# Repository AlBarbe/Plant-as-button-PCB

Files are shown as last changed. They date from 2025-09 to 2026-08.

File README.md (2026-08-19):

<!-- HEADER -->
# Plant as Button — PCB 🌱🔌

Wouldn't be cool to use as a plant a touch sensor? Now it has a proper board to live on.
This repo hosts the hardware side of the project — the companion firmware (the code that actually reads the plant's touch) lives in [Plant-as-button](https://github.com/AlBarbe/Plant-as-button).

<!-- TABLE OF CONTENTS -->
<!--
<details>
  <summary>Table of contenent</summary>
    <ul>
      <li></li><a href="#introduction">Introduction</a></li>
      <li></li><a href="#how-it-works">How it works</a></li>
      <li></li><a href="#repository-structure">Repository structure</a></li>
      <li></li><a href="#status--known-issues">Status & known issues</a></li>
    </ul>
</details>
-->
<!-- INTRODUCTION -->
## Introduction

This is my first PCB design, done in KiCad 9. The idea was to give the plant-as-button concept a real, standalone board instead of a breadboard: an ESP32-S3 module, its own power supply, and a driver stage so the "button" can actually control something (an RGBWW LED strip) when the plant is touched.

The board has been manufactured and it works. Every opinion or suggestion is more than welcome!!

<!-- HOW IT WORKS -->
## How it works
- ### Concept
  The board is built around an ESP32-S3-MINI-1 module, using the same capacitive touch trick described in the firmware repo: a touch-capable GPIO is wired to a pad, meant to be connected (by a simple cable) to the soil near the plant's roots. When a person touches the plant, the capacitance seen on that GPIO changes, and the microcontroller reads it as a "press".

- ### Power
  The board can be powered either from USB-C or from an external 12V supply (screw terminal), with a power mux (TPS2116) automatically selecting between the two. From there, two buck converters step the voltage down to 5V and then 3.3V for the MCU and the rest of the logic. The 12V input is protected with a TVS diode, and the USB data lines have their own ESD protection.

- ### LED driver
  Five low-side MOSFETs let the ESP32 switch a common-anode RGBWW LED strip (Red, Green, Blue, Warm White, Cool White), connected via a 6-pin screw terminal. The idea is the same as the firmware's trigger class: on touch, on release, or after a given time, drive one of the channels.

- ### Debug breakout
  Basically every GPIO of the module is broken out to its own test pad on the silkscreen (labeled with the pin function, not just a generic reference), on top of the usual RESET/BOOT buttons. This turned out to be very handy, see below.

## Repository structure
- `PAB_V1.kicad_pro / .kicad_sch / .kicad_pcb` — the KiCad 9 project (schematic + 4-layer PCB, single sheet).
- `Libraries/` — symbols, footprints and 3D models used by the project (kept local so the repo is self-contained).
- `Datasheets/` — datasheets of the main parts used.
- `BOM.ods` — bill of materials.

## Status & known issues
The board has been fabricated and is working. There is one known bug: the USB-UART bridge (CP2102) is not wired correctly to the ESP32-S3, so programming/monitoring through the on-board USB-C via the CP2102 doesn't work.
It's not a dead end though — the ESP32-S3 has its own native USB, and since every GPIO (including the native USB D+/D-) is broken out to a test pad, the board can still be flashed and debugged by using those pins directly, bypassing the CP2102 entirely.

## Implementation
Firmware-wise, this board is meant to be paired with the code from [Plant-as-button](https://github.com/AlBarbe/Plant-as-button): the touch pad on this PCB is where the plant's cable connects, and the LED terminal is a ready-made output for whatever trigger logic you build on top of it.

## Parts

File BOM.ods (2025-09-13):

DESIGNATOR | QTY | VALUE | MANUF. PART N° | MANUFACTUR | PACKAGE | DESCRIPTION | LINKS
U1 | 1 |  | ESP32-WROOM-32E-N4 | Espressif System | 38-SMD Module | RF TXRX MOD BT WIFI TH SMD | https://www.digikey.com/en/products/detail/espressif-systems/ESP32-WROOM-32E-N4/11613125, https://www.snapeda.com/parts/ESP32-WROOM-32E%20(4MB)/Espressif%20Systems/view-part/?company=Private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
U2 | 1 |  | CP2102NA02GQFN20 | Silicon Labs |  | USB Bridge, USB to UART USB 2.0 UART Interface 20-QFN (3x3) | https://www.digikey.com/en/products/detail/silicon-labs/CP2102N-A02-GQFN20/9863475, https://www.snapeda.com/parts/CP2102NA02GQFN20/Silicon%20Labs/view-part/?t=cp2102&ab_test_case=b
U3 | 1 |  | USBLC6-2SC6 | STMicroelectronics | SOT-23-6 | 17V Clamp 5A (8/20µs) Ipp Tvs Diode Surface Mount SOT-23-6 | https://www.digikey.com/en/products/detail/stmicroelectronics/USBLC6-2SC6/1040559, https://www.snapeda.com/parts/USBLC6-2SC6/STMicroelectronics/view-part/?t=usblc6&ab_test_case=b
U4 | 1 |  | AP63205WU-7 | Diodes Incorporated | TSOT-23-6 | Buck Switching Regulator IC Positive Fixed 5V 1 Output 2A SOT-23-6 Thin, TSOT-23-6 | https://www.digikey.com/en/models/9858424
Q3 | 1 |  | AO3400A | Alpha & Omega Semiconductor Inc. | SOT-23-3 | N-Channel 30 V 5.7A (Ta) 1.4W (Ta) Surface Mount SOT-23-3
S1-S2 | 2 |  | PTS647SN50SMTR2 LFS | C&K |  | Tactile Switch SPST-NO Top Actuated Surface Mount
C1 | 1 | 10 µF | CL31B106KAHNNNE | Samsung Electro-Mechanics | 1206 (3216 Metric) | 10 µF ±10% 25V Ceramic Capacitor X7R 1206 (3216 Metric)
C2-C3 | 2 | 22 µF | CL31A226KAHNNNE | Samsung Electro-Mechanics | 1206 (3216 Metric) | 22 µF ±10% 25V Ceramic Capacitor X5R 1206 (3216 Metric)
C4 | 1 | 0.1 µF | GRM155R71E104KE14D | Murata Electronics | 0402 (1005 Metric) | 0.1 µF ±10% 25V Ceramic Capacitor X7R 0402 (1005 Metric)

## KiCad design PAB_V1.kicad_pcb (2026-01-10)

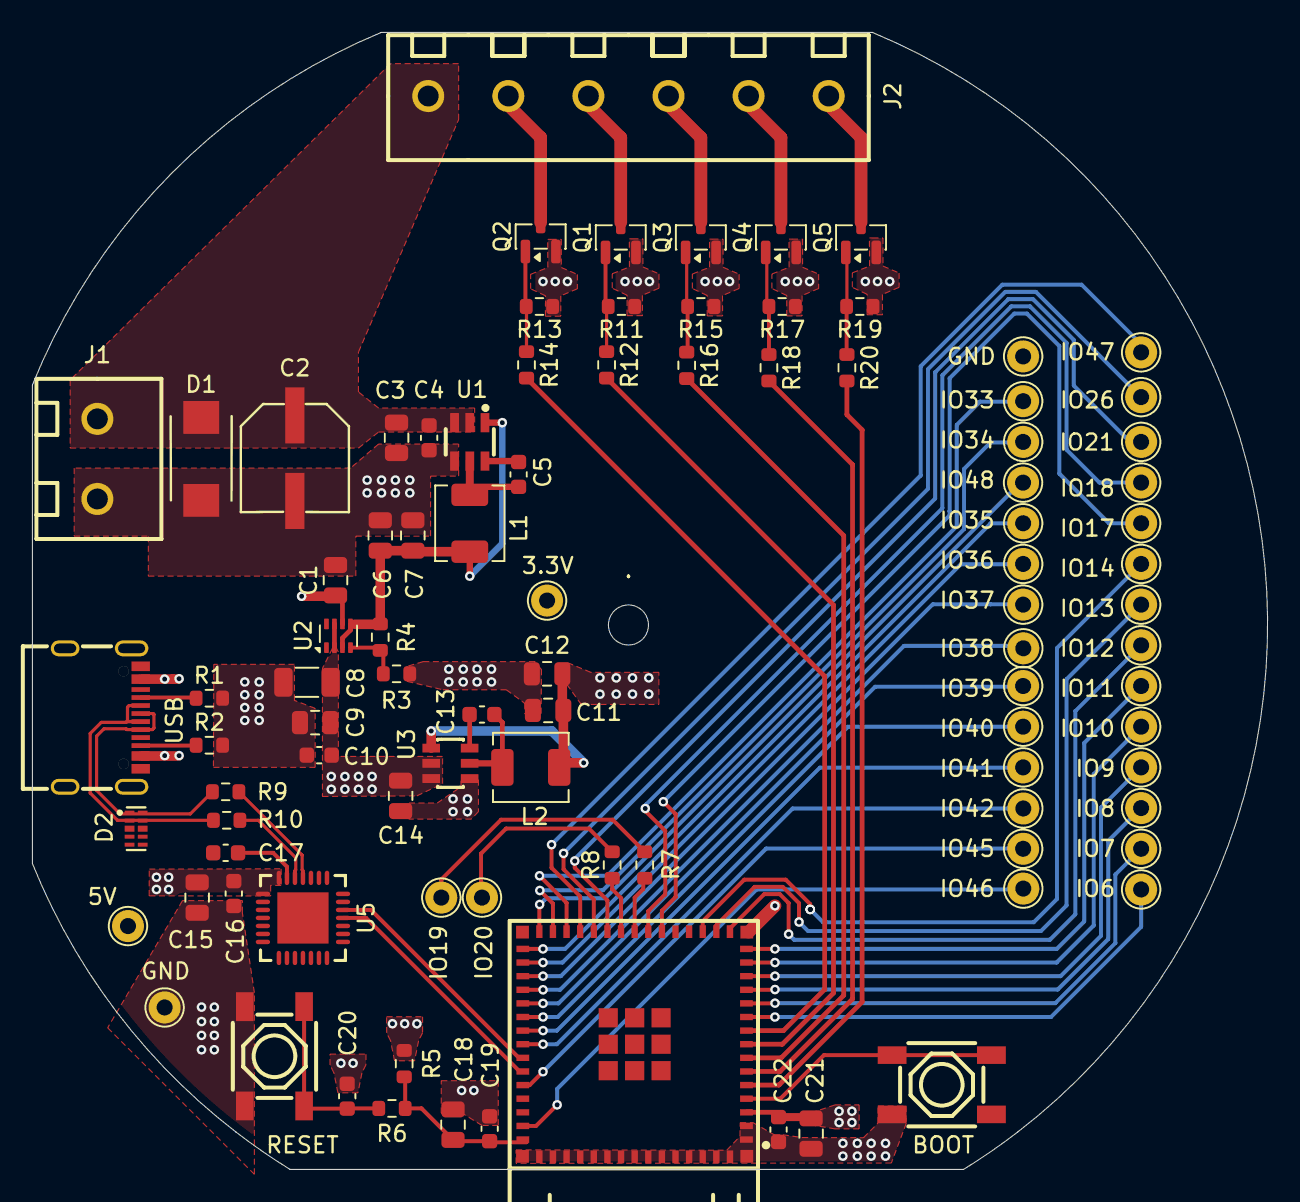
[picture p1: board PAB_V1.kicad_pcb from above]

Board: 4 copper layers, 77.1 x 71.0 mm, 95 parts (0 on the bottom side), 67 nets.

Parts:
3.3V, 5V: Conn_01x01; TestPoint_THTPad_D2.0mm_Drill1.0mm
.: MountingHole_2.5mm
BOOT: BOOT; SW-SMD_4P-L5.2-W5.2-P3.70-LS6.5
C1, C3, C9, C14: 10μF; C_0805_2012Metric
C2: MA25V220M6X8; CAP-SMD_BD6.3-L6.6-W6.6-LS7.3-FD
C4, C5, C10, C13, C16, C17, C19, C20, C22: 100nF; C_0603_1608Metric
C6, C7, C11, C12, C21: 22μF; C_0805_2012Metric
C8: 47μF; C_1206_3216Metric
C15, C18: 1μF; C_0805_2012Metric
D1: SMBJ15CA; SMB_L4.6-W3.6-LS5.3-BI
D2: TPD4E05U06DQAR; USON-10_L2.5-W1.0-P0.50-BL
GND: Conn_01x01; TestPoint_THTPad_D2.0mm_Drill1.0mm
GND#2: Conn_01x01; TestPoint_THTPad_D2.0mm_Drill1.0mm
IO6, IO7, IO8, IO9, IO10, IO11, IO12, IO13, IO14, IO17, IO18, IO19, IO20, IO21, IO26, IO33, IO34, IO35, IO36, IO37, IO38, IO39, IO40, IO41, IO42, IO45, IO46, IO47, IO48: Conn_01x01; TestPoint_THTPad_D2.0mm_Drill1.0mm
J1: Screw_Terminal_01x02; CONN-TH_WJ126V-5.0-2P
J2: Screw_Terminal_01x06; CONN-TH_6P-P5.00_WJ126V-5.0-6P
L1, L2: 4.7μH; L_TechFuse_SL0420
Q1, Q2, Q3, Q4, Q5: AO3400A; SOT-23
R1, R2: 5.1KΩ; R_0603_1608Metric
R3, R4: 24KΩ; R_0603_1608Metric
R5: 10KΩ; R_0603_1608Metric
R6, R7, R8: 0Ω; R_0603_1608Metric
R9, R10, R12, R14, R16, R18, R20: 22Ω; R_0603_1608Metric
R11, R13, R15, R17, R19: 100KΩ; R_0603_1608Metric
RESET: RESET; SW-SMD_4P-L5.2-W5.2-P3.70-LS6.5
U1: AP63205WU-7; TSOT-23-6_L2.9-W1.6-P0.95-LS2.8-BL
U2: TPS2116DRL; SOT-583-8
U3: AP63203WU-7; TSOT-26_L2.9-W1.6-P0.95-LS2.8-BL
U4: ESP32-S3-MINI-1-N4R2; BULETM-SMD_ESP32-S3-MINI-1-N8
U5: CP2102-GMR; WQFN-28_L5.0-W5.0-P0.50-BL-EP3.2
USB: TYPE-C16PIN; USB-C-SMD_TYPE-C16PIN

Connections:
+3.3V: 3.3V.1, C11.1, C12.1, C21.2, C22.1, L2.2, R5.2, U3.1 (FB), U4.3 (3V3)
+5V: 5V.1, C8.2, C9.2, C10.2, C14.1, C15.1, C16.1, U2.2 (VOUT), U2.7 (VOUT), U3.2 (EN), U3.3 (VIN), U5.7 (REGIN), U5.8 (VBUS)
+5V_PS: C6.1, C7.1, L1.1, R4.2, U1.1 (FB), U2.3 (VIN1), U2.5 (MODE)
+5V_USB: C1.1, D2.4 (D2+), D2.7 (NC), U2.6 (VIN2), USB.A4B9 (VBUS), USB.B4A9 (VBUS)
+12V: C2.1, C3.2, C4.2, D1.2 (A), J1.1, J2.6, U1.2 (EN), U1.3 (VIN)
/BOOT: BOOT.3, BOOT.4, U4.4 (IO0)
/EN: C18.2, C19.1, R5.1, R6.2, U4.45 (EN)
Blue: J2.3, Q3.3 (D)
C_White: J2.1, Q5.3 (D)
GND: BOOT.2, C1.2, C2.2, C3.1, C4.1, C6.2, C7.2, C8.1, C9.1, C10.1, C11.2, C12.2, C14.2, C15.2, C16.2, C17.1, C18.1, C19.2, C20.2, C21.1, C22.2, D1.1 (K), D2.3 (GND), D2.8 (GND), GND.1, GND#2.1, J1.2, Q1.2 (S), Q2.2 (S), Q3.2 (S), Q4.2 (S), Q5.2 (S), R1.2, R2.2, R3.1, R11.1, R13.1, R15.1, R17.1, R19.1, RESET.1, RESET.2, U1.4 (GND), U2.1 (GND), U3.4 (GND), U4.1 (GND), U4.2 (GND), U4.42 (GND), U4.43 (GND), U4.46 (GND), U4.47 (GND), U4.48 (GND), U4.49 (GND), U4.50 (GND), U4.51 (GND), U4.52 (GND), U4.53 (GND), U4.54 (GND), U4.55 (GND), U4.56 (GND), U4.57 (GND), U4.58 (GND), U4.59 (GND), U4.60 (GND), U4.GND, U5.3 (GND), USB.1 (SHELL), USB.2 (SHELL), USB.3 (SHELL), USB.4 (SHELL), USB.A1B12 (GND), USB.B1A12 (GND)
GPIO1: R20.2, U4.5 (IO1)
GPIO2: R18.2, U4.6 (IO2)
GPIO3: R16.2, U4.7 (IO3)
GPIO4: R12.2, U4.8 (IO4)
GPIO5: R14.2, U4.9 (IO5)
GPIO6: IO6.1, U4.10 (IO6)
GPIO7: IO7.1, U4.11 (IO7)
GPIO8: IO8.1, U4.12 (IO8)
GPIO9: IO9.1, U4.13 (IO9)
GPIO10: IO10.1, U4.14 (IO10)
GPIO11: IO11.1, U4.15 (IO11)
GPIO12: IO12.1, U4.16 (IO12)
GPIO13: IO13.1, U4.17 (IO13)
GPIO14: IO14.1, U4.18 (IO14)
GPIO17: IO17.1, U4.21 (IO17)
GPIO18: IO18.1, U4.22 (IO18)
GPIO19: IO19.1, R7.2
GPIO20: IO20.1, R8.1
GPIO21: IO21.1, U4.25 (IO21)
GPIO26: IO26.1, U4.26 (IO26)
GPIO33: IO33.1, U4.28 (IO33)
GPIO34: IO34.1, U4.29 (IO34)
GPIO35: IO35.1, U4.31 (IO35)
GPIO36: IO36.1, U4.32 (IO36)
GPIO37: IO37.1, U4.33 (IO37)
GPIO38: IO38.1, U4.34 (IO38)
GPIO39: IO39.1, U4.35 (IO39)
GPIO40: IO40.1, U4.36 (IO40)
GPIO41: IO41.1, U4.37 (IO41)
GPIO42: IO42.1, U4.38 (IO42)
GPIO45: IO45.1, U4.41 (IO45)
GPIO46: IO46.1, U4.44 (IO46)
GPIO47: IO47.1, U4.27 (IO47)
GPIO48: IO48.1, U4.30 (IO48)
Green: J2.5, Q2.3 (D)
unnamed: C20.1, R6.1, RESET.3, RESET.4
unnamed: Q1.1 (G), R11.2, R12.1
unnamed: Q2.1 (G), R13.2, R14.1
unnamed: Q3.1 (G), R15.2, R16.1
unnamed: Q4.1 (G), R17.2, R18.1
unnamed: Q5.1 (G), R19.2, R20.1
unnamed: C5.1, U1.6 (BST)
unnamed: C5.2, L1.2, U1.5 (SW)
unnamed: R3.2, R4.1, U2.4 (PR1)
unnamed: C13.2, U3.6 (BST)
unnamed: C13.1, L2.1, U3.5 (SW)
unnamed: R7.1, U4.23 (IO19)
unnamed: R8.2, U4.24 (IO20)
unnamed: C17.2, U5.6 (VDD)
unnamed: R1.1, USB.A5 (CC1)
unnamed: R2.1, USB.B5 (CC2)
RXD0: U4.40 (RXD0), U5.25 (RXD)
Red: J2.4, Q1.3 (D)
TXD0: U4.39 (TXD0), U5.26 (TXD)
USB_DN: D2.2 (D1-), D2.9 (NC), R10.1, R10.2, U5.5 (D-), USB.A7 (DN1), USB.B7 (DN2)
USB_DP: D2.1 (D1+), D2.10 (NC), R9.1, R9.2, U5.4 (D+), USB.A6 (DP1), USB.B6 (DP2)
W_White: J2.2, Q4.3 (D)

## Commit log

2025-09-13 Project start: created power supply
    [BOM.ods, PAB_V1.kicad_pcb, PAB_V1.kicad_sch]
2025-09-13 First upload: Creation of the project, created power supply related circuit
2025-09-16 Added ESP32-S3FN8, and made some circuitry
    [PAB_V1.kicad_sch]
2025-09-24 Choose esp32-s3-mini1 instead, and AP63203 as 5V to 3.3V instead ldo converter
    [PAB_V1.kicad_sch]
2025-09-27 added esp32 and uart circuitry, cleaned chart
    [PAB_V1.kicad_sch]
2025-09-27 Compleated first design, mst be checked and added properly connector
    [PAB_V1.kicad_sch]
2025-09-30 Added TVS to 12V input, reorganized names, reorganized structures
    [PAB_V1.kicad_sch]
2025-10-03 Changed whole symbol and footprint library, used easyeda2kicad converted from jlc part.
    [PAB_V1.kicad_sch]
2025-10-03 Added most of the component footprint need specs for capacitor types and dimension
    [PAB_V1.kicad_sch]
2025-10-19 Macbook project test upload
    [PAB_V1.kicad_sch]
2025-10-19 Added Bulk capacitor, corrected stuff, checked things
    [PAB_V1.kicad_sch]
2025-10-19 Added schematic PDF
2025-10-21 Correction to basic component value
    [PAB_V1.kicad_sch]
2025-10-21 added decoupling capacitors, added capacitor footprint
    [PAB_V1.kicad_sch]
2025-10-24 filled part/footprint file (proto bom file)
    [PAB_V1.kicad_sch]
2025-10-25 resolving error, added bom file
    [PAB_V1.kicad_sch]
2025-11-02 organized netclasses
    [PAB_V1.kicad_pcb, PAB_V1.kicad_sch]
2025-11-04 starting placing component
    [PAB_V1.kicad_pcb, PAB_V1.kicad_sch]
2025-11-06 going on with PCB design
    [PAB_V1.kicad_pcb, PAB_V1.kicad_sch]
2025-11-07 going on with pcb layout
    [PAB_V1.kicad_pcb, PAB_V1.kicad_sch]
2026-01-01 going on with connections
    [PAB_V1.kicad_pcb, PAB_V1.kicad_sch]
2026-01-10 3D file path correction
    [PAB_V1.kicad_pcb]
2026-01-10 reorganized text layout
    [PAB_V1.kicad_pcb]
